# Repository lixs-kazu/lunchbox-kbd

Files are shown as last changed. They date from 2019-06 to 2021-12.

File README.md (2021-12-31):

# lunchbox-kbd　egg52で不満だった部分を変更したキーボード

具体的には

・使用頻度が極めて低かったため、小指の外側の一列を削除

・できるだけ指の移動量がを減らすため、縦のキーピッチを１８mmに変更。そのため通常のキーキャップは使用できない可能性がある（キーキャップを削る事によって使用可能）chocスイッチの場合問題なく使用できる。

・親指を使用した入力時、他のキーに手が当たるのを防ぐ為に親指部分の角度を変更。

・親指部分の４キーを内側に２mm移動。

・人差し指部分のキーが押しにくかったため、中指から6.5mmの差をつけた。

・小指部分のキーも同様だったので、中指から20mmの差をつけた。

・アクリル箱組ケース制作するときに可能な限りサイドパネルの枚数を減らしたいので、外形を五角形とした。

・ケーブル横出しは狭いスペースで作業するときに邪魔になるので上側にケーブルがでるように変更。

・LEDとOLEDに対応。



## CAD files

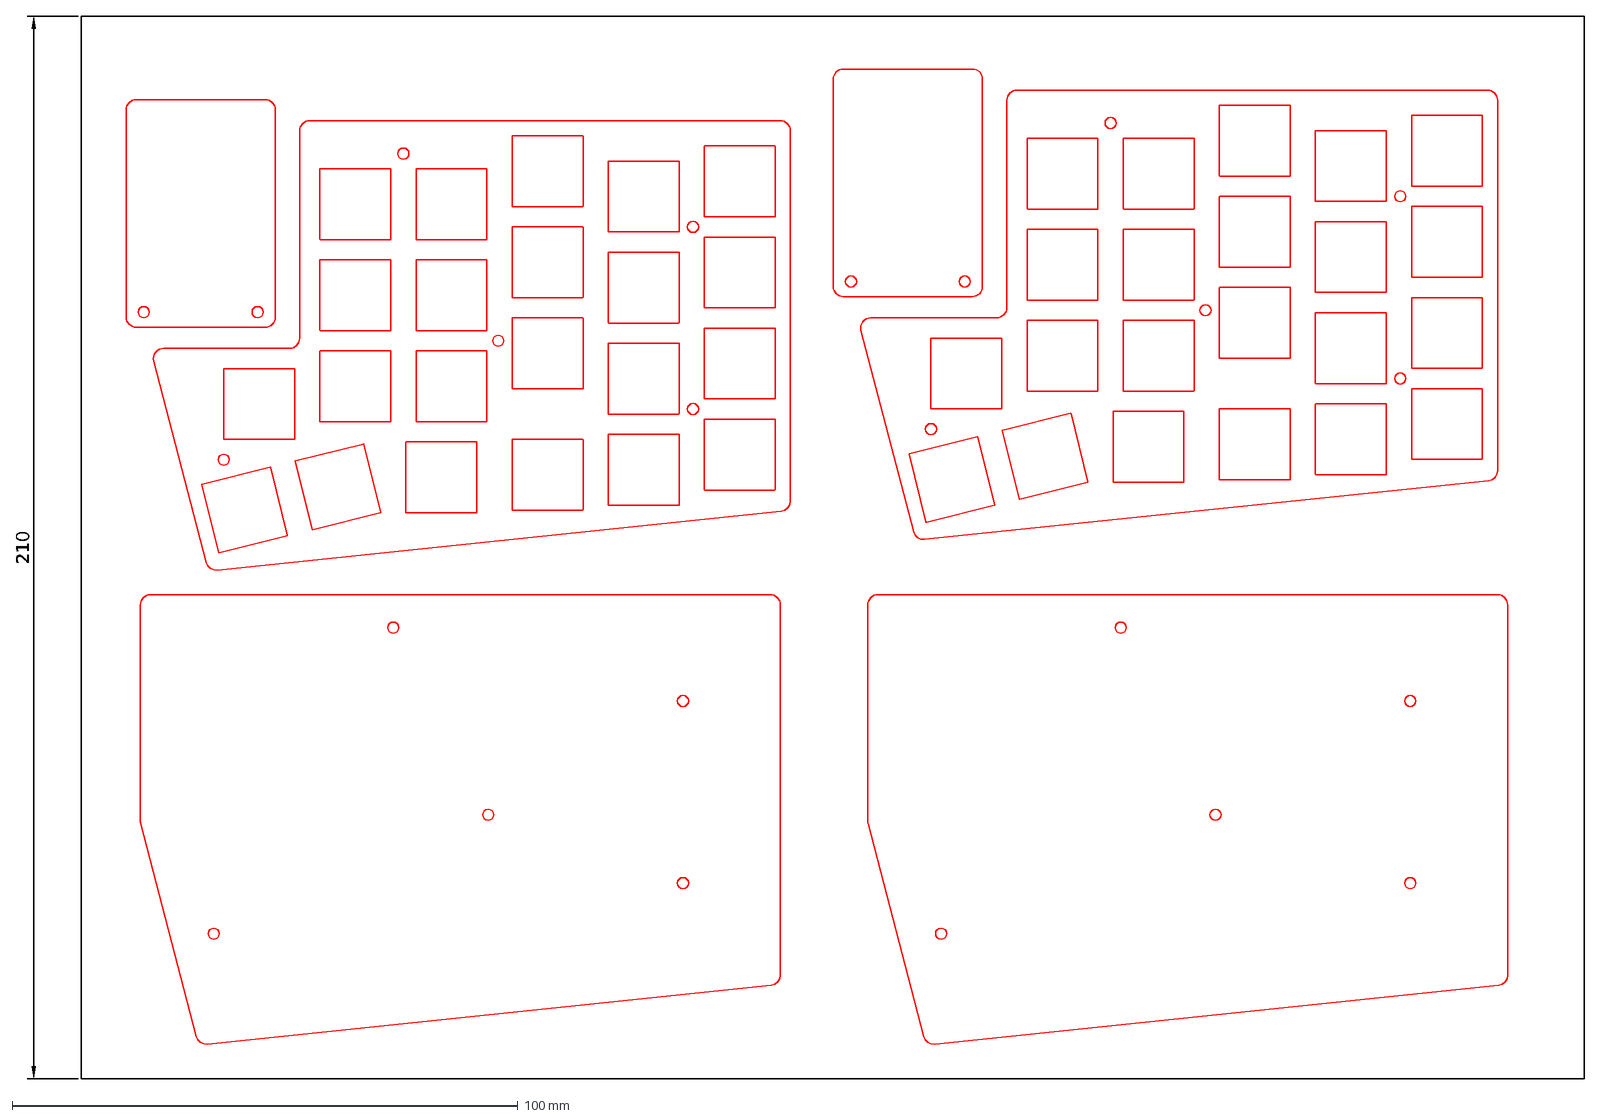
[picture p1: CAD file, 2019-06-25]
l(a)unchbox date/A4kbd-case.dxf
210

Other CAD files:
l(a)unchbox date/A4kbd-case.dwg

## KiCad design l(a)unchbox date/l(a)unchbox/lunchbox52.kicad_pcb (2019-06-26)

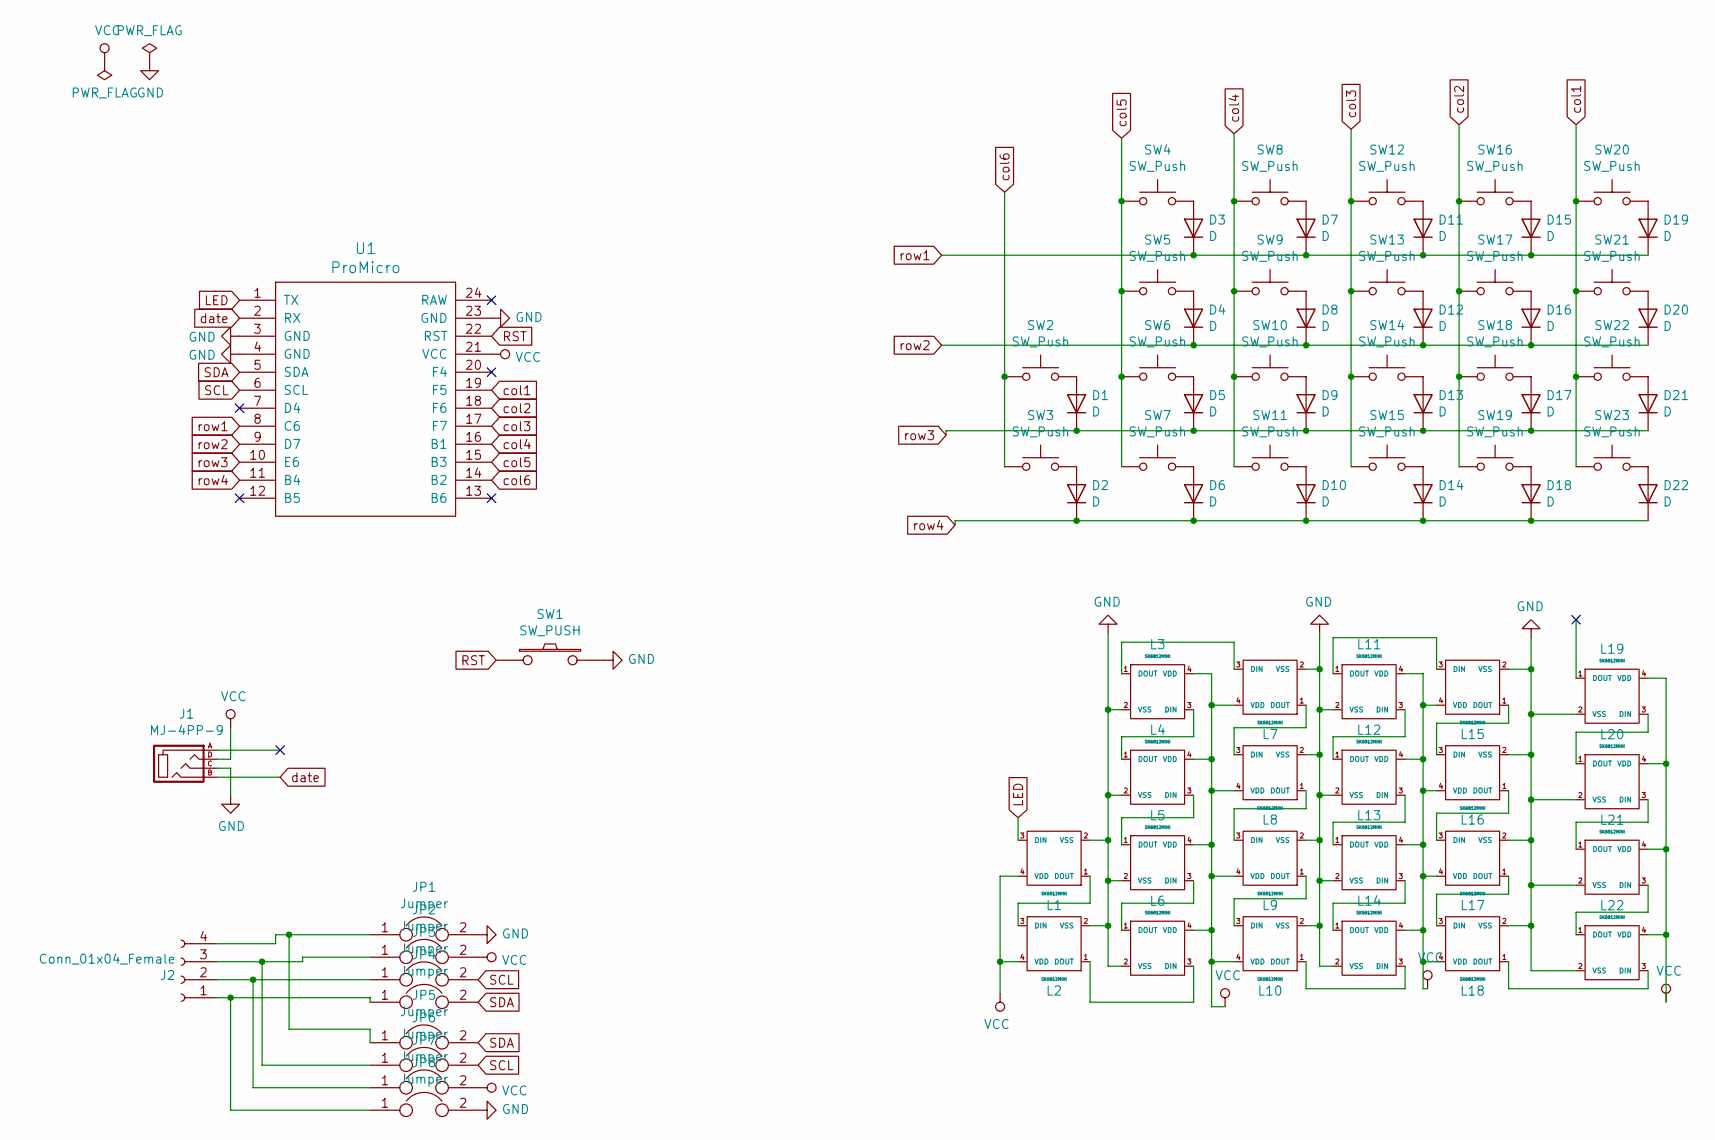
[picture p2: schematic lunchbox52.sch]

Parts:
D1, D2, D3, D4, D5, D6, D7, D8, D9, D10, D11, D12, D13, D14, D15, D16, D17, D18, D19, D20, D21, D22: D; D3_TH_SMD
J1: MJ-4PP-9
J2: Conn_01x04_Female; OLED
JP1, JP2, JP3, JP4, JP5, JP6, JP7, JP8: Jumper
L1, L2, L3, L4, L5, L6, L7, L8, L9, L10, L11, L12, L13, L14, L15, L16, L17, L18, L19, L20, L21, L22: SK6812MINI; SK6812MINI_rev
SW1: SW_PUSH; ResetSW
SW2, SW3, SW4, SW5, SW6, SW7, SW8, SW9, SW10, SW11, SW12, SW13, SW14, SW15, SW16, SW17, SW18, SW19, SW20, SW21, SW22, SW23: SW_Push; MX_PG1350_FLIP_HOLES
U1: ProMicro; ProMicro_v2

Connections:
GND: J1.C, JP1.2, JP8.2, L1.2 (VSS), L2.2 (VSS), L3.2 (VSS), L4.2 (VSS), L5.2 (VSS), L6.2 (VSS), L7.2 (VSS), L8.2 (VSS), L9.2 (VSS), L10.2 (VSS), L11.2 (VSS), L12.2 (VSS), L13.2 (VSS), L14.2 (VSS), L15.2 (VSS), L16.2 (VSS), L17.2 (VSS), L18.2 (VSS), L19.2 (VSS), L20.2 (VSS), L21.2 (VSS), L22.2 (VSS), SW1.2, U1.3 (GND), U1.4 (GND), U1.23 (GND)
LED: L1.3 (DIN), U1.1 (TX)
unnamed: D1.2 (A), SW2.2
unnamed: D2.2 (A), SW3.2
unnamed: D3.2 (A), SW4.2
unnamed: D4.2 (A), SW5.2
unnamed: D5.2 (A), SW6.2
unnamed: D6.2 (A), SW7.2
unnamed: D7.2 (A), SW8.2
unnamed: D8.2 (A), SW9.2
unnamed: D9.2 (A), SW10.2
unnamed: D10.2 (A), SW11.2
unnamed: D11.2 (A), SW12.2
unnamed: D12.2 (A), SW13.2
unnamed: D13.2 (A), SW14.2
unnamed: D14.2 (A), SW15.2
unnamed: D15.2 (A), SW16.2
unnamed: D16.2 (A), SW17.2
unnamed: D17.2 (A), SW18.2
unnamed: D18.2 (A), SW19.2
unnamed: D19.2 (A), SW20.2
unnamed: D20.2 (A), SW21.2
unnamed: D21.2 (A), SW22.2
unnamed: D22.2 (A), SW23.2
unnamed: J2.1, JP4.1, JP8.1
unnamed: J2.2, JP3.1, JP7.1
unnamed: J2.3, JP2.1, JP6.1
unnamed: J2.4, JP1.1, JP5.1
unnamed: L1.1 (DOUT), L2.3 (DIN)
unnamed: L2.1 (DOUT), L6.3 (DIN)
unnamed: L3.1 (DOUT), L7.3 (DIN)
unnamed: L3.3 (DIN), L4.1 (DOUT)
unnamed: L4.3 (DIN), L5.1 (DOUT)
unnamed: L5.3 (DIN), L6.1 (DOUT)
unnamed: L7.1 (DOUT), L8.3 (DIN)
unnamed: L8.1 (DOUT), L9.3 (DIN)
unnamed: L10.1 (DOUT), L14.3 (DIN)
unnamed: L9.1 (DOUT), L10.3 (DIN)
unnamed: L11.1 (DOUT), L15.3 (DIN)
unnamed: L11.3 (DIN), L12.1 (DOUT)
unnamed: L12.3 (DIN), L13.1 (DOUT)
unnamed: L13.3 (DIN), L14.1 (DOUT)
unnamed: L15.1 (DOUT), L16.3 (DIN)
unnamed: L16.1 (DOUT), L17.3 (DIN)
unnamed: L17.1 (DOUT), L18.3 (DIN)
unnamed: L18.1 (DOUT), L22.3 (DIN)
unnamed: L19.3 (DIN), L20.1 (DOUT)
unnamed: L20.3 (DIN), L21.1 (DOUT)
unnamed: L21.3 (DIN), L22.1 (DOUT)
RST: SW1.1, U1.22 (RST)
SCL: JP3.2, JP6.2, U1.6 (SCL)
SDA: JP4.2, JP5.2, U1.5 (SDA)
VCC: J1.D, JP2.2, JP7.2, L1.4 (VDD), L2.4 (VDD), L3.4 (VDD), L4.4 (VDD), L5.4 (VDD), L6.4 (VDD), L7.4 (VDD), L8.4 (VDD), L9.4 (VDD), L10.4 (VDD), L11.4 (VDD), L12.4 (VDD), L13.4 (VDD), L14.4 (VDD), L15.4 (VDD), L16.4 (VDD), L17.4 (VDD), L18.4 (VDD), L19.4 (VDD), L20.4 (VDD), L21.4 (VDD), L22.4 (VDD), U1.21 (VCC)
col1: SW20.1, SW21.1, SW22.1, SW23.1, U1.19 (F5)
col2: SW16.1, SW17.1, SW18.1, SW19.1, U1.18 (F6)
col3: SW12.1, SW13.1, SW14.1, SW15.1, U1.17 (F7)
col4: SW8.1, SW9.1, SW10.1, SW11.1, U1.16 (B1)
col5: SW4.1, SW5.1, SW6.1, SW7.1, U1.15 (B3)
col6: SW2.1, SW3.1, U1.14 (B2)
date: J1.B, U1.2 (RX)
row1: D3.1 (K), D7.1 (K), D11.1 (K), D15.1 (K), D19.1 (K), U1.8 (C6)
row2: D4.1 (K), D8.1 (K), D12.1 (K), D16.1 (K), D20.1 (K), U1.9 (D7)
row3: D1.1 (K), D5.1 (K), D9.1 (K), D13.1 (K), D17.1 (K), D21.1 (K), U1.10 (E6)
row4: D2.1 (K), D6.1 (K), D10.1 (K), D14.1 (K), D18.1 (K), D22.1 (K), U1.11 (B4)

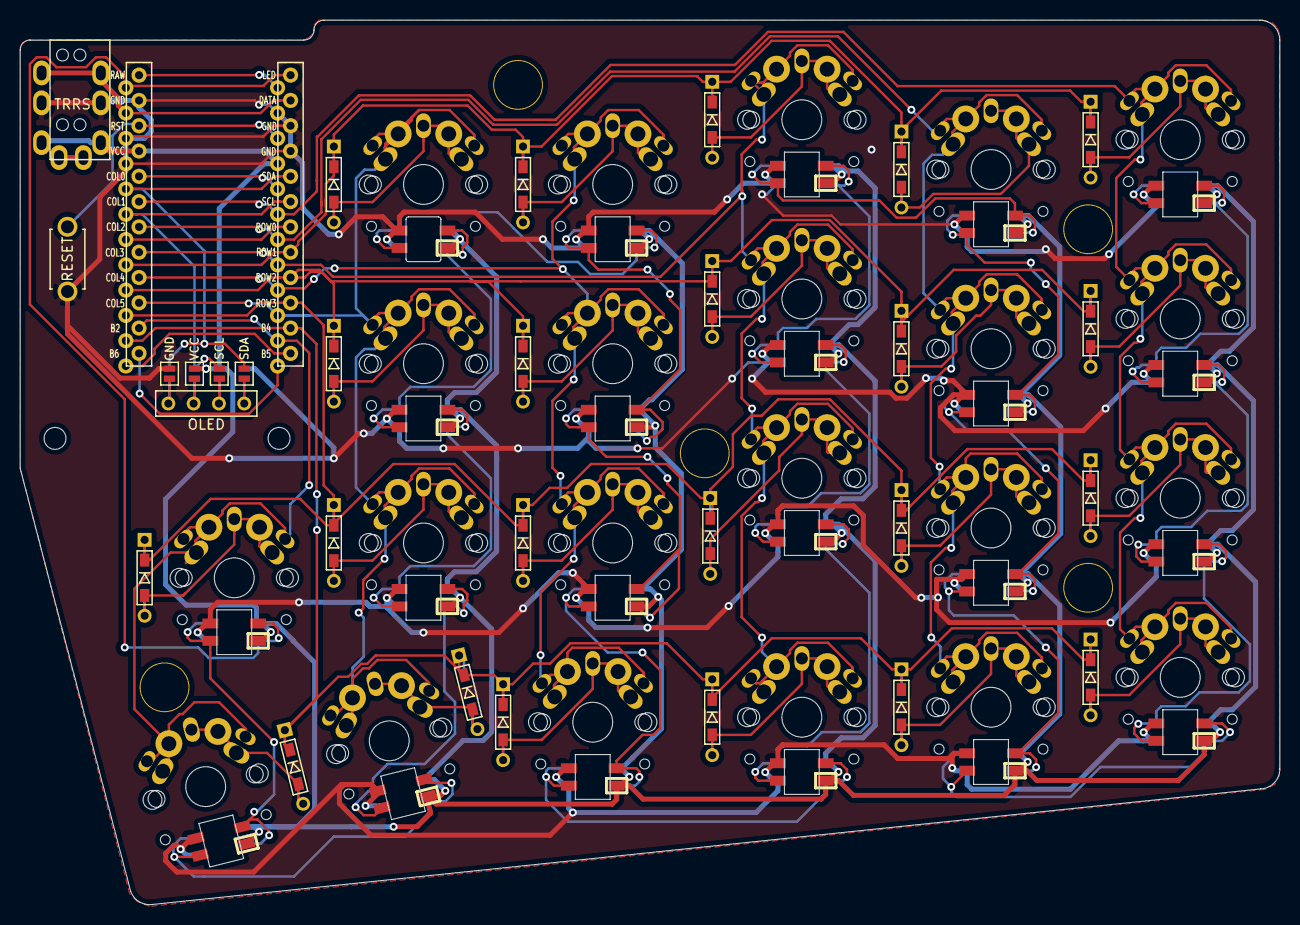
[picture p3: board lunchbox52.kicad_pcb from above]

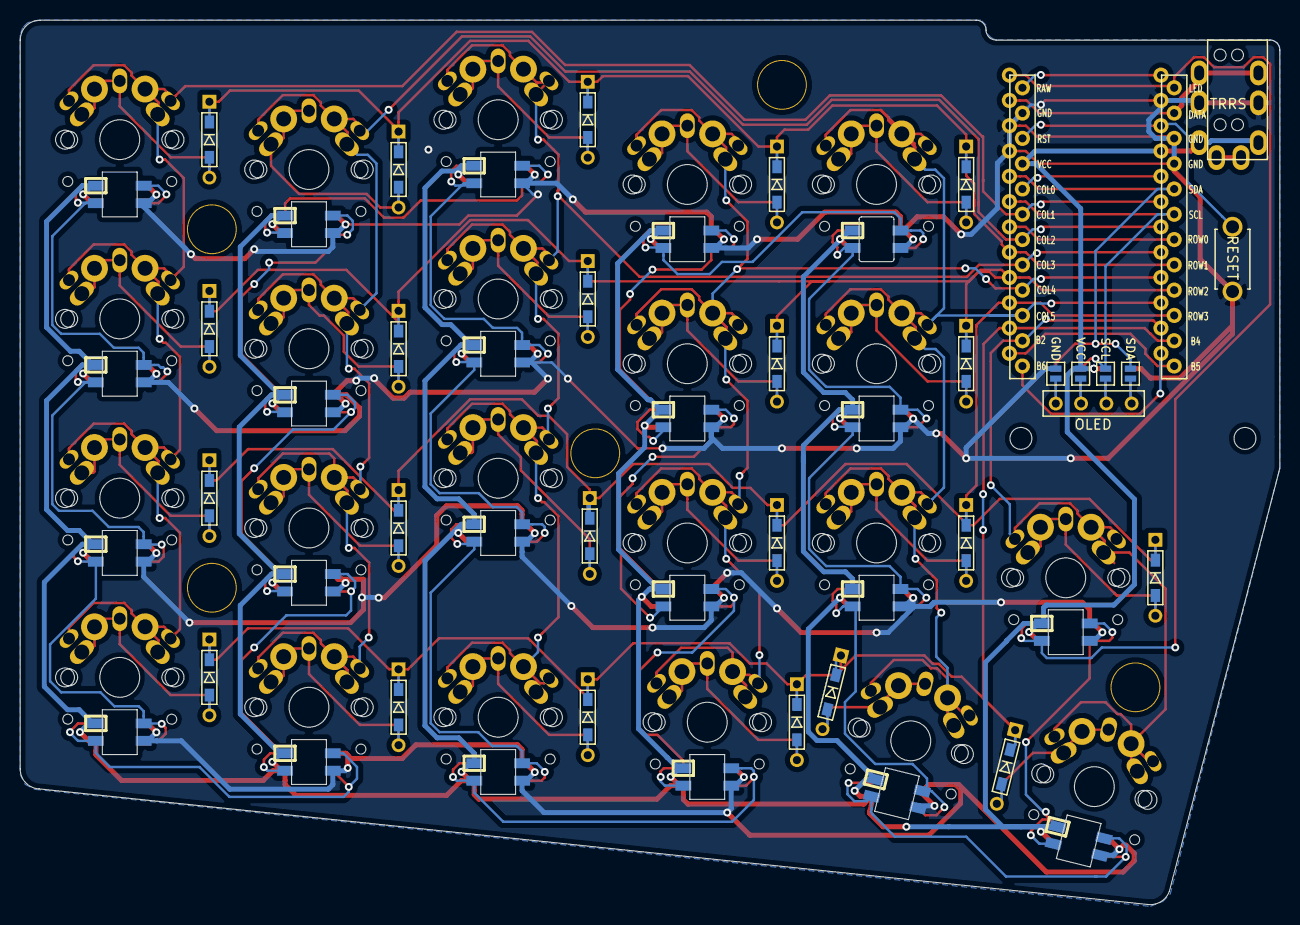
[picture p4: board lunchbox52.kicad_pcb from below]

Board: 2 copper layers, 126.5 x 88.8 mm, 83 parts (4 on the bottom side), 64 nets.

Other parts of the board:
Ref**: Val**; HOLE
Ref**#2, Ref**#3, Ref**#4, Ref**#5: Val**; HOLE
